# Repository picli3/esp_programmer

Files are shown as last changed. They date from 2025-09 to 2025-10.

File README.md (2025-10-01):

 </br>
[certification OSHW](https://certification.oshwa.org/pe000001.html)

---
# ESP32 Prog Lite

This module was designed to optimize the programming of ESP32 devices in production environments. It emerged as a solution to a common problem: the need to efficiently and cost-effectively program electronic products that don't require a USB port for final operation.

| | |
|:---:|:---:|
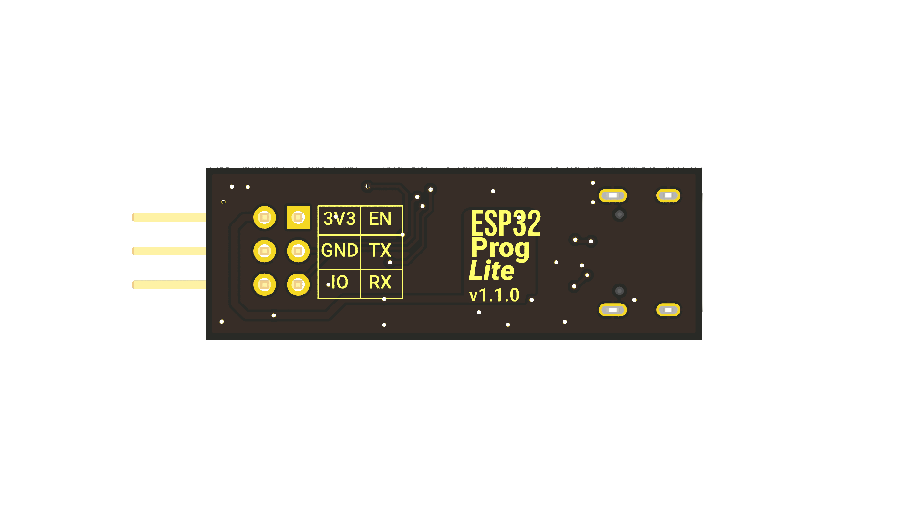
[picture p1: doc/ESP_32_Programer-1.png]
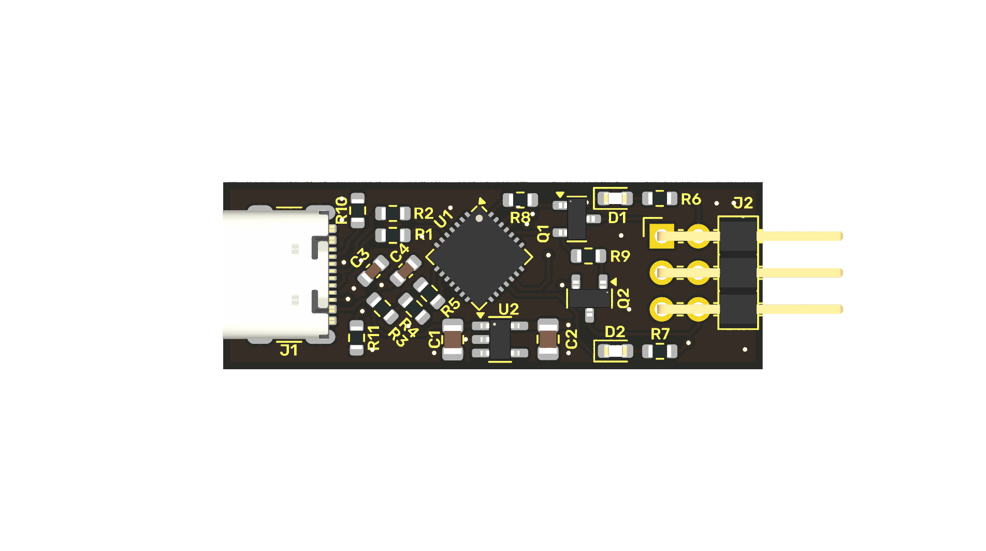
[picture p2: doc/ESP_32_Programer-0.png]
|  ||

## The USB problem in production

For devices that run on alkaline batteries or are programmed only once at the factory, a USB connector and its integrated serial converter, such as the popular CP2102N, represent an unnecessary cost. In mass production, these components add up to a considerable expense. For example, in a production run of 1,000 units, a converter at $2 USD per piece increases the total cost by $2,000 USD, not including the other associated components and the space they take up on the board.

In a real-world case, a customer looking to update their PCB design had a USB-C converter on their board. By eliminating these circuits and offering our solution, which uses Pogo-Pin clips, we were able to significantly reduce their costs and production time.

## A simple and efficient design

Our main objective was to simplify the programming process, making it as small and efficient as possible. We were inspired by the **ESP-programmer**, a device known for its JTAG programming and debugging capabilities. However, our goal was not to replicate all of its features, but rather to create a minimalist tool focused exclusively on production programming that would allow for seamless integration and rapid adoption on any assembly line.

This approach has allowed us to develop a programmer that offers a low-cost, high-performance solution for mass production of ESP32-based products.

## Why choose this programmer?

* **Cost savings:** Eliminates the need for integrated USB-to-serial converters on each board, dramatically reducing unit costs in mass production.

* **Space optimization:** Its compact design frees up valuable PCB space, ideal for products with size constraints.

* **Production efficiency:** Enables quick and easy programming using Pogo-Pin connectors, streamlining the manufacturing process.

## BOM
| **#** | **Reference** | **Description** | **Qty** | **Part #** | **Manufacturer** | **LCSC**  |
|--- |--- |--- |---  |--- |--- |--- |
| 1 | C3 | 10V 4.7uF X5R ±10% 0603 Multilayer Ceramic Capacitors MLCC - SMD/SMT ROHS | 1 | CL10A475KP8NNNC | Samsung Electro-Mechanics | C1705 |
| 2 | C4 | 50V 100nF X7R ±10% 0603 Multilayer Ceramic Capacitors MLCC - SMD/SMT ROHSr | 1 | CC0603KRX7R9BB104 | YAGEO | C14663 |
| 3 | C1,C2 | 50V 1uF X7R ±10% 0805 Multilayer Ceramic Capacitors MLCC - SMD/SMT ROHS | 2 | CL21B105KBFNNNE | Samsung Electro-Mechanics | C28323 |
| 4 | J2 | Right Angle Pin Header 2.5mm 6mm 6P -40℃~+105℃ 2.54mm 2 Black Brass 2x3P Push-Pull,P=2.54mm Pin Headers ROHS | 1 | PH2.54-07-03PWS | XUNPU | C7501617  |
| 5 | J1 | USB 2.0-only 14P Type-C Receptacle connector | 1 | TYPE-C 16PIN 2MD(073) | SHOU HAN | C2765186  |
| 6 | D1,D2 | 25mA 80mcd~220mcd Independent Diode 615nm~630nm -30℃~+85℃ Red 130° 65mW 1.6V~2.6V 0603 LED Indication - Discrete ROHS | 2 | NCD0603R1 | NATIONSTAR | C84263 |
| 7 | U1 | USB to UART QFN-28-EP(5x5) USB Converters ROHS | 1 | CP2102N-A02-GQFN28R | SILICON LABS | C964632 |
| 8 | U2 | 600mA low dropout linear regulator, with enable pin, 3.8V-6V input voltage range, 3.3V fixed positive output, SOT-23-5 | 1 | AP2112K-3.3TRG1 | Diodes Incorporated | C51118 |
| 9 | Q1,Q2 | 40V 200mW 100@10mA,1V 200mA NPN SOT-23 Bipolar (BJT) ROHS | 2 | MMBT3904 | TWGMC | C727127 |
| 10 | R1,R2 | 100mW Thick Film Resistors 75V ±1% ±400ppm/℃ 10Ω 0603 Chip Resistor - Surface Mount ROHS | 2 | 0603WAF100JT5E | UNI-ROYAL | C22859 |
| 11 | R3 | 100mW Thick Film Resistor 75V ±100ppm/℃ ±1% 22.1kΩ 0603 Chip Resistor - Surface Mount ROHS | 1 | RC0603FR-0722K1L | YAGEO | C137768 |
| 12 | R4 | 100mW Thick Film Resistor 75V ±100ppm/℃ ±1% 47.5kΩ 0603 Chip Resistor - Surface Mount ROHS | 1 | RC0603FR-0747K5L | YAGEO | C137715 |
| 13 | R5 | Thin Film Resistors - SMD 1K ohm 1% 1/10W | 1 | ARG03FTC1001 | Viking | C217840 |
| 14 | R6,R7 | Thick Film Resistors - SMD 330 Ohms 100mW 0603 1% | 2 | RC0603FR-07330RL | YAGEO | C105881 |
| 15 | R8,R9 | 100mW ±100ppm/℃ ±1% 10kΩ 0603 Chip Resistor - Surface Mount ROHS | 2 | RMC16K103FTP | KAMAYA | C323556 |
| 16 | R10,R11 | 100mW Thick Film Resistor 75V ±100ppm/℃ ±1% 5.1kΩ 0603 Chip Resistor - Surface Mount ROHS | 2 | 0603WAF5101T5E | UNI-ROYAL | C23186 |

## Generate panel

To do this it is required [Kikit](https://github.com/yaqwsx/KiKit?tab=readme-ov-file)

```sh
kikit panelize \
    --layout 'grid; rows: 6; cols: 2; space: 2mm' \
    --tabs 'fixed; width: 3mm; vcount: 2' \
    --cuts 'mousebites; drill: 0.5mm; spacing: 1mm; offset: 0.2mm; prolong: 0.5mm' \
    --framing 'railstb; width: 5mm; space: 3mm;' \
    --tooling '3hole; hoffset: 2.5mm; voffset: 2.5mm; size: 1.5mm' \
    --fiducials '3fid; hoffset: 5mm; voffset: 2.5mm; coppersize: 2mm; opening: 1mm;' \
    --text 'simple; text: MaykolRey.com; anchor: mt; voffset: 2.5mm; hjustify: center; vjustify: center;' \
    --text2 'simple; text: Created on {date}; anchor: mb; voffset: -2.5mm; hjustify: center; vjustify: center;' \
    --post 'millradius: 1mm' \
    ESP_32_Programer.kicad_pcb panel/panel.kicad_pcb
```
## Licence



Author: Maykol Rey

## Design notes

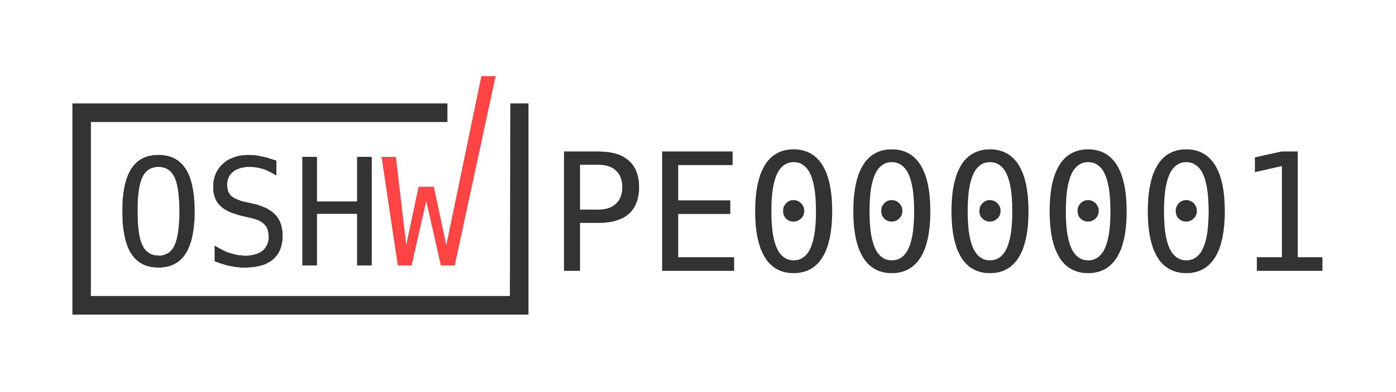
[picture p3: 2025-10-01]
doc/certification-mark-PE000001-wide.png

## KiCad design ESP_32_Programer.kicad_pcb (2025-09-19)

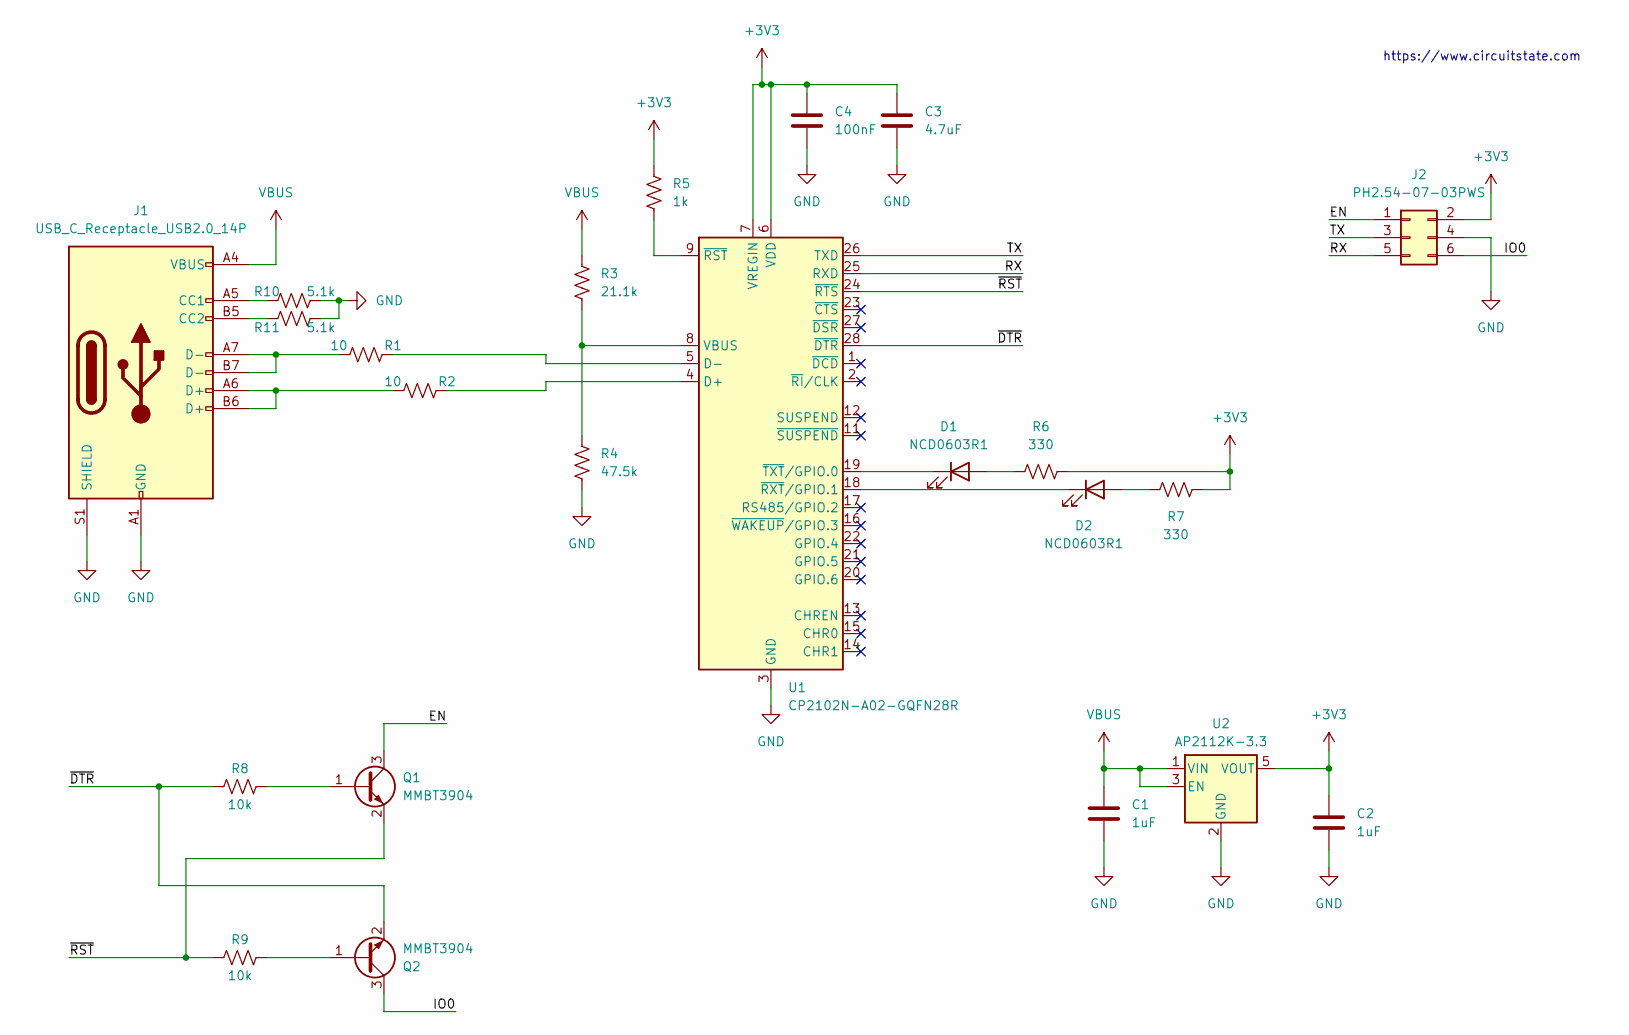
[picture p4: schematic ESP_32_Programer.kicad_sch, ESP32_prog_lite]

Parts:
C1, C2: 1uF; C_0805_2012Metric; Part # CL21B105KBFNNNE; LCSC C28323
C3: 4.7uF; C_0603_1608Metric; Part # CL10A475KP8NNNC; LCSC C1705
C4: 100nF; C_0603_1608Metric; Part # CC0603KRX7R9BB104; LCSC C14663
D1, D2: NCD0603R1; LED_0603_1608Metric; Part # NCD0603R1; LCSC C84263
J1: USB_C_Receptacle_USB2.0_14P; USB_C_Receptacle_GCT_USB4105-xx-A_16P_TopMnt_Horizontal; Part # TYPE-C 16PIN 2MD(073); LCSC C2765186
J2: PH2.54-07-03PWS; PinHeader_2x03_P2.54mm_Horizontal; Part # PH2.54-07-03PWS; LCSC C7501617
Q1, Q2: MMBT3904; SOT-23; Part # MMBT3904; LCSC C727127
R1, R2: 10; R_0603_1608Metric; Tolerance ±1%; Part # 0603WAF100JT5E; LCSC C22859
R3: 21.1k; R_0603_1608Metric; Tolerance ±1%; Part # RC0603FR-0722K1L; LCSC C137768
R4: 47.5k; R_0603_1608Metric; Tolerance ±1%; Part # RC0603FR-0747K5L; LCSC C137715
R5: 1k; R_0603_1608Metric; Part # ARG03FTC1001; LCSC C217840
R6, R7: 330; R_0603_1608Metric; Part # RC0603FR-07330RL; LCSC C105881
R8, R9: 10k; R_0603_1608Metric; Tolerance ±1%; Part # RMC16K103FTP; LCSC C323556
R10, R11: 5.1k; R_0603_1608Metric; Tolerance ±1%; Part # 0603WAF5101T5E; LCSC C23186
U1: CP2102N-A02-GQFN28R; QFN-28-1EP_5x5mm_P0.5mm_EP3.35x3.35mm; Part # CP2102N-A02-GQFN28R; LCSC C964632
U2: AP2112K-3.3; SC-74A-5_1.55x2.9mm_P0.95mm; Part # AP2112K-3.3TRG1; LCSC C51118

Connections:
+3V3: C2.1, C3.1, C4.1, J2.2, R5.1, R6.2, R7.2, U1.6 (VDD), U1.7 (VREGIN), U2.5 (VOUT)
/EN: J2.1, Q1.3 (C)
/IO0: J2.6, Q2.3 (C)
/RX: J2.5, U1.25 (RXD)
/TX: J2.3, U1.26 (TXD)
/~DTR: Q2.2 (E), R8.1, U1.28 (~DTR)
/~RST: Q1.2 (E), R9.1, U1.24 (~RTS)
GND: C1.2, C2.2, C3.2, C4.2, J1.A1 (GND), J1.A12 (GND), J1.B1 (GND), J1.B12 (GND), J1.S1 (SHIELD), J2.4, R4.2, R10.2, R11.2, U1.3 (GND), U1.29 (GND), U2.2 (GND)
unnamed: D1.2 (A), R6.1
unnamed: D1.1 (K), U1.19 (~TXT/GPIO.0)
unnamed: D2.2 (A), R7.1
unnamed: D2.1 (K), U1.18 (~RXT/GPIO.1)
unnamed: J1.A5 (CC1), R10.1
unnamed: J1.B5 (CC2), R11.1
unnamed: J1.A6 (D+), J1.B6 (D+), R2.1
unnamed: J1.A7 (D-), J1.B7 (D-), R1.1
unnamed: Q1.1 (B), R8.2
unnamed: Q2.1 (B), R9.2
unnamed: R2.2, U1.4 (D+)
unnamed: R1.2, U1.5 (D-)
unnamed: R3.2, R4.1, U1.8 (VBUS)
unnamed: R5.2, U1.9 (~RST)
VBUS: C1.1, J1.A4 (VBUS), J1.A9 (VBUS), J1.B4 (VBUS), J1.B9 (VBUS), R3.1, U2.1 (VIN), U2.3 (EN)

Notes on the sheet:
https://www.circuitstate.com

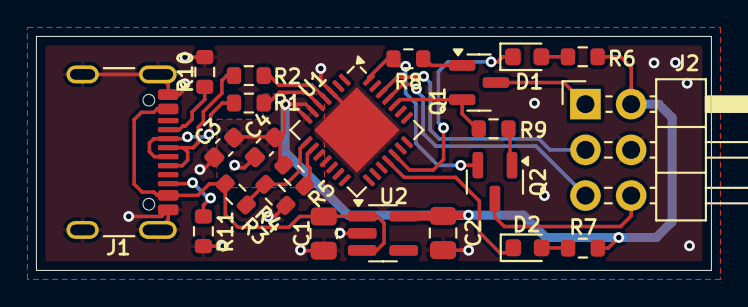
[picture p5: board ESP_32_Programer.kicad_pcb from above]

Board: 2 copper layers, 37.5 x 13.0 mm, 23 parts (0 on the bottom side), 23 nets.

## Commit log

2025-06-18 completando esquematico
    [ESP_32_Programer.kicad_pcb, ESP_32_Programer.kicad_sch]
2025-06-23 completando el diseño de la pcb
    [ESP_32_Programer.kicad_pcb, ESP_32_Programer.kicad_sch]
2025-06-24 corrigiendo error en USB y completando BOM
    [ESP_32_Programer.kicad_sch]
2025-06-24 completando PCB
    [ESP_32_Programer.kicad_pcb]
2025-07-12 completando version fabricada en PCBWay
    [ESP_32_Programer.kicad_pcb]
2025-09-19 actualizando documentacion generando version v1.1.0
    [ESP_32_Programer.kicad_pcb, ESP_32_Programer.kicad_sch]
2025-09-19 agregando script para panel
2025-09-20 actualizando README agregando BOM
